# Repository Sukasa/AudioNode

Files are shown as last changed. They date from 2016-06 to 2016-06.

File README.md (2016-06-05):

# AudioNode
ESP8266/Teensy/VS1063a-based streaming audio node with MQTT integration

This project is the motherboard for a multi-mcu audio endpoint.  It uses three CPUs; a VS1063a does the heavy lifting for the audio decoding and is operated as a slave co-processor by the ESP8266.  A Teensy 3.2 also hangs off the ESP8266, being used as a sub-processor for the touch interface (7 capacitive touch points).  The ESP controls these two processors through a shared SPI bus, with the ESP as the bus master and the Teensy/VS1063a as SPI slaves.

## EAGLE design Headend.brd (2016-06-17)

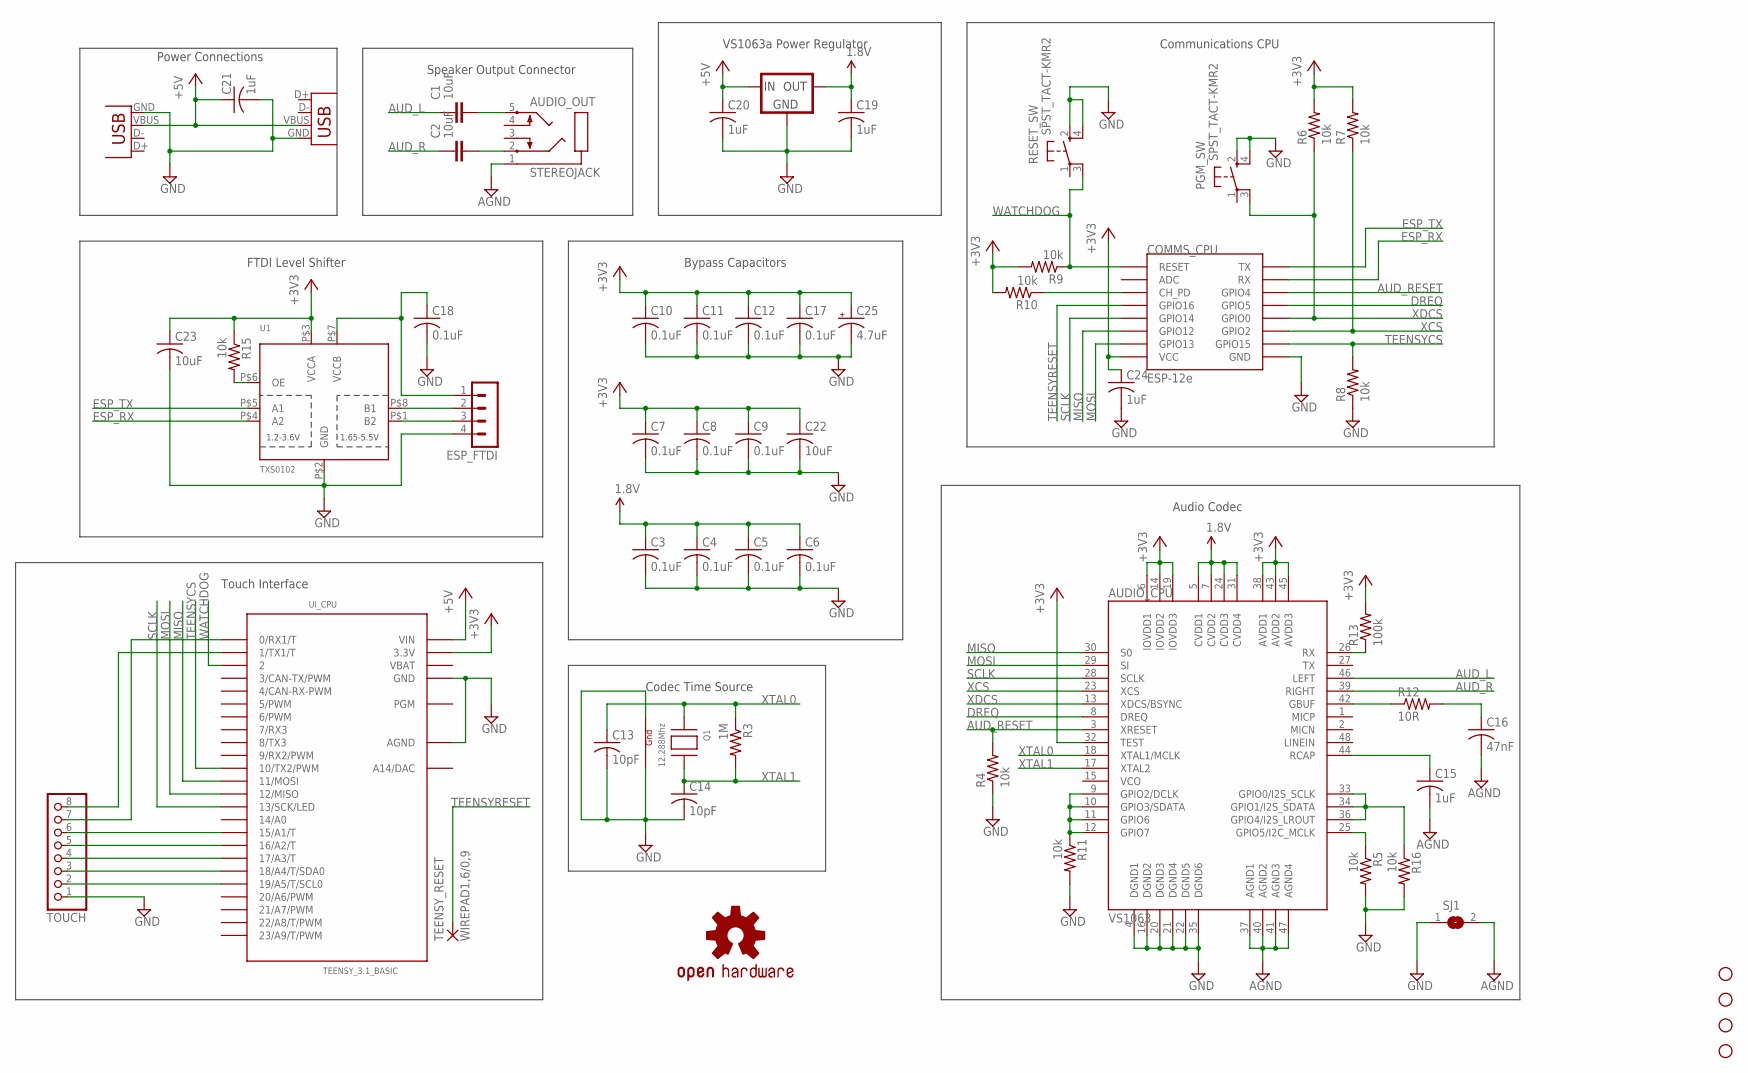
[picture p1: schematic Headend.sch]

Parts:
AUDIO_CPU: VS1063; LQFP-48
AUDIO_OUT: STEREOJACK; STX3100
C1, C2: 10uF; C805
C3, C4, C5, C6, C7, C8, C9, C10, C11, C12, C17, C18: 0.1uF; C0402
C13, C14: 10pF; C0402
C15, C24: 1uF; C0402
C16: 47nF; C0402
C19, C20, C21: 1uF; C0603
C22, C23: 10uF; C0402
C25: 4.7uF; PANASONIC_A
COMMS_CPU: ESP-12e; ESP12-SMD
ESP_FTDI: MA04-1
LOGO1: OSHW-LOGOL; OSHW-LOGO-L
PGM_SW: SPST_TACT-KMR2; KMR2
POWER_IN: USBSMD; USB-MINIB
Q1: 12.288Mhz; NX3225
R3: 1M; R0402
R4, R5, R6, R7, R8, R10, R11, R15, R16: 10k; R0402
R9: 10k; R0603
R12: 10R; R0402
R13: 100k; R0402
RESET_SW: SPST_TACT-KMR2; KMR2
SJ1: SJ
SPEAKER_PWR2: USB-A-S
STANDOFF1, STANDOFF2, STANDOFF3, STANDOFF4: STAND-OFF
TEENSY_RESET: WIREPAD1,6/0,9; 1,6/0,9
TOUCH: PINHD-1X8BIG; 1X08-BIG
U1: TXS0102; VFSOP-8
U2: AP7313; SOT23
UI_CPU: TEENSY_3.1_BASIC

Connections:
1.8V: AUDIO_CPU.5 (CVDD1), AUDIO_CPU.7 (CVDD2), AUDIO_CPU.24 (CVDD3), AUDIO_CPU.31 (CVDD4), C3.1, C4.1, C5.1, C6.1, C19.1, U2.2 (OUT)
+3V3: AUDIO_CPU.6 (IOVDD1), AUDIO_CPU.14 (IOVDD2), AUDIO_CPU.19 (IOVDD3), AUDIO_CPU.32 (TEST), AUDIO_CPU.38 (AVDD1), AUDIO_CPU.43 (AVDD2), AUDIO_CPU.45 (AVDD3), C7.1, C8.1, C9.1, C10.1, C11.1, C12.1, C17.1, C22.1, C23.1, C24.1, C25.+, COMMS_CPU.VCC, R6.2, R7.2, R9.2, R10.2, R13.2, R15.1, U1.P$3 (VCCA), UI_CPU.3.3V, UI_CPU.3.3V1 (3.3V)
+5V: C20.1, C21.1, POWER_IN.VBUS, SPEAKER_PWR2.VBUS, U2.1 (IN), UI_CPU.VIN
AGND: AUDIO_CPU.37 (AGND1), AUDIO_CPU.40 (AGND2), AUDIO_CPU.41 (AGND3), AUDIO_CPU.47 (AGND4), AUDIO_OUT.1, C15.2, C16.2, SJ1.2
AUD_L: AUDIO_CPU.46 (LEFT), C1.1
AUD_R: AUDIO_CPU.39 (RIGHT), C2.1
AUD_RESET: AUDIO_CPU.3 (XRESET), COMMS_CPU.GPIO4, R4.2
DREQ: AUDIO_CPU.8 (DREQ), COMMS_CPU.GPIO5
ESP_RX: COMMS_CPU.RXD0 (RX), U1.P$4 (A2)
ESP_TX: COMMS_CPU.TXD0 (TX), U1.P$5 (A1)
GND: AUDIO_CPU.4 (DGND1), AUDIO_CPU.16 (DGND2), AUDIO_CPU.20 (DGND3), AUDIO_CPU.21 (DGND4), AUDIO_CPU.22 (DGND5), AUDIO_CPU.35 (DGND6), C3.2, C4.2, C5.2, C6.2, C7.2, C8.2, C9.2, C10.2, C11.2, C12.2, C13.2, C14.2, C17.2, C18.2, C19.2, C20.2, C21.2, C22.2, C23.2, C24.2, C25.-, COMMS_CPU.GND, ESP_FTDI.4, PGM_SW.2 (S), PGM_SW.4 (S1), POWER_IN.GND, Q1.2 (G2), Q1.4 (G1), R4.1, R5.2, R8.1, R11.2, R16.2, RESET_SW.2 (S), RESET_SW.4 (S1), SJ1.1, SPEAKER_PWR2.GND, TOUCH.1, U1.P$2 (GND), U2.3 (GND), UI_CPU.AGND, UI_CPU.GND, UI_CPU.GND1 (GND)
MISO: AUDIO_CPU.30 (S0), COMMS_CPU.GPIO12, UI_CPU.11 (11/MOSI)
MOSI: AUDIO_CPU.29 (SI), COMMS_CPU.GPIO13, UI_CPU.12 (12/MISO)
unnamed: TOUCH.6, UI_CPU.15/A1 (15/A1/T)
unnamed: TOUCH.5, UI_CPU.16/A2 (16/A2/T)
unnamed: TOUCH.4, UI_CPU.17/A3 (17/A3/T)
unnamed: TOUCH.3, UI_CPU.18/A4 (18/A4/T/SDA0)
unnamed: TOUCH.2, UI_CPU.19/A5 (19/A5/T/SCL0)
unnamed: R15.2, U1.P$6 (OE)
unnamed: AUDIO_OUT.2, C2.2
unnamed: AUDIO_OUT.5, C1.2
unnamed: TOUCH.8, UI_CPU.1 (1/TX1/T)
unnamed: AUDIO_CPU.9 (GPIO2/DCLK), AUDIO_CPU.10 (GPIO3/SDATA), AUDIO_CPU.11 (GPIO6), AUDIO_CPU.12 (GPIO7), R11.1
unnamed: COMMS_CPU.CH_PD, R10.1
unnamed: AUDIO_CPU.33 (GPIO0/I2S_SCLK), AUDIO_CPU.34 (GPIO1/I2S_SDATA), AUDIO_CPU.36 (GPIO4/I2S_LROUT), R16.1
unnamed: AUDIO_CPU.44 (RCAP), C15.1
unnamed: AUDIO_CPU.42 (GBUF), R12.1
unnamed: C16.1, R12.2
unnamed: AUDIO_CPU.26 (RX), R13.1
unnamed: ESP_FTDI.2, U1.P$8 (B1)
unnamed: ESP_FTDI.3, U1.P$1 (B2)
unnamed: C18.1, ESP_FTDI.1, U1.P$7 (VCCB)
unnamed: TOUCH.7, UI_CPU.0 (0/RX1/T)
unnamed: AUDIO_CPU.25 (GPIO5/I2C_MCLK), R5.1
SCLK: AUDIO_CPU.28 (SCLK), COMMS_CPU.GPIO14, UI_CPU.13 (13/SCK/LED)
TEENSYCS: COMMS_CPU.GPIO15, R8.2, UI_CPU.10 (10/TX2/PWM)
TEENSYRESET: COMMS_CPU.GPIO16, TEENSY_RESET.1
VBAT: UI_CPU.VBAT
WATCHDOG: COMMS_CPU.RESET, R9.1, RESET_SW.3 (P1), UI_CPU.2
XCS: AUDIO_CPU.23 (XCS), COMMS_CPU.GPIO2, R7.1
XDCS: AUDIO_CPU.13 (XDCS/BSYNC), COMMS_CPU.GPIO0, PGM_SW.3 (P1), R6.1
XTAL0: AUDIO_CPU.18 (XTAL1/MCLK), C13.1, Q1.1 (X1), R3.1
XTAL1: AUDIO_CPU.17 (XTAL2), C14.1, Q1.3 (X2), R3.2

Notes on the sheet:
Power Connections
FTDI Level Shifter
Speaker Output Connector
VS1063a Power Regulator
Bypass Capacitors
Touch Interface
Codec Time Source
Communications CPU
Audio Codec

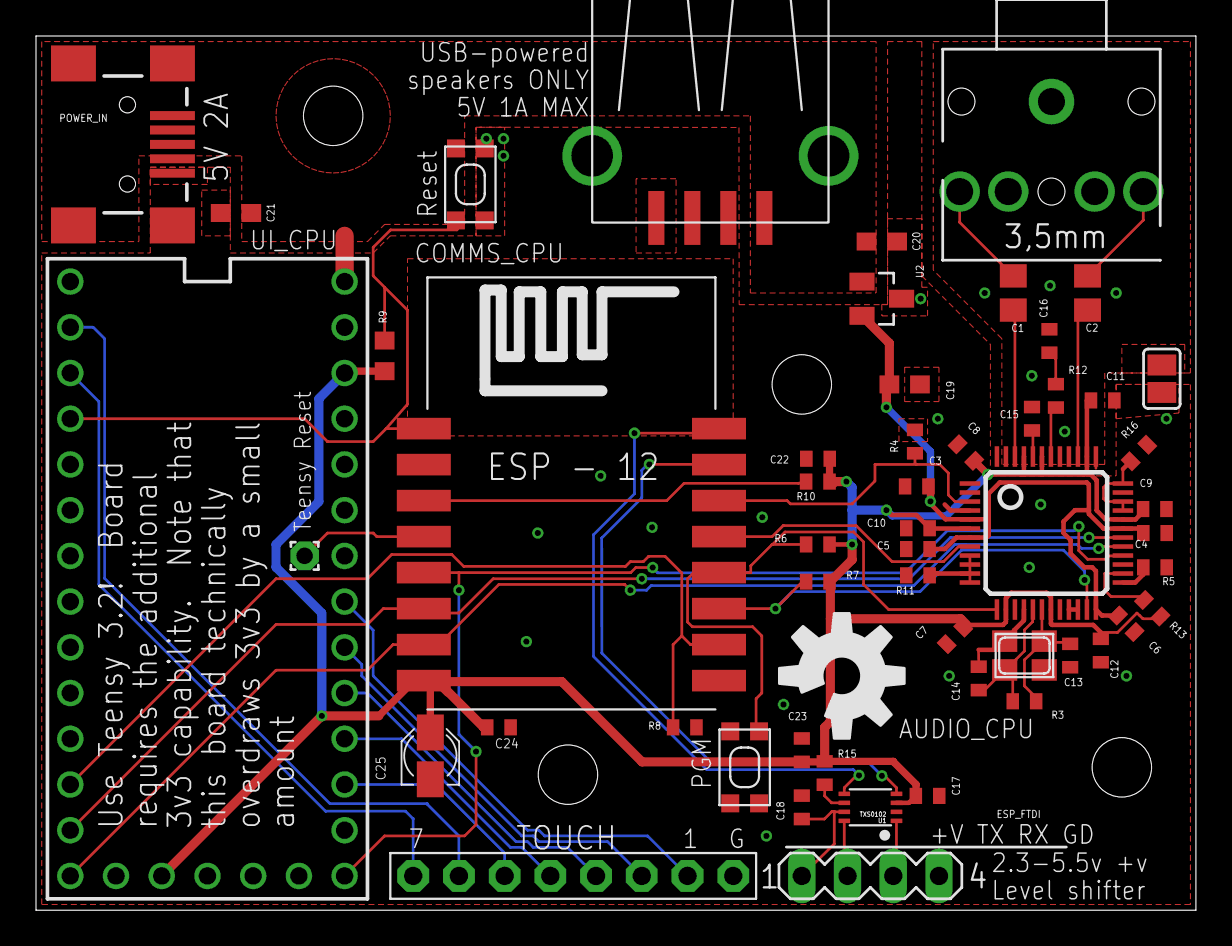
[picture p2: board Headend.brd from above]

Board: 2 copper layers, 64.4 x 48.6 mm, 58 parts (0 on the bottom side), 42 nets.

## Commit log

2016-06-05 Add to Git
    [Headend.brd, Headend.sch]
2016-06-05 Update board design
    [Headend.brd, Headend.sch]
2016-06-06 Update board with further tweaks
    [Headend.brd, Headend.sch]
2016-06-11 Update design, clean up spurious resistor between 3v3 and Gnd, clean up some routing
    [Headend.brd, Headend.sch]
2016-06-17 Updated with more reddit feedback
    [Headend.brd, Headend.sch]

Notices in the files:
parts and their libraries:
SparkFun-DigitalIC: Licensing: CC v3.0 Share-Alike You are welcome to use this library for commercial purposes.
